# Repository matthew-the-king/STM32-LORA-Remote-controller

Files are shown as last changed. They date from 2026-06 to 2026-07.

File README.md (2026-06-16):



THE PROJECT
This is my LORA radio controller project! I wanted to make this because I am currently building a drone
that requires a capable LORA radio.
I have posted the Gerber files and BOM so you can produce your own functioning LORA radio controller.
The controller has two joysticks, two switches, and two potentiometers for inputs.  I also added
a buzzer to notify people when events happen, like connecting to a device.  In the PCB step file I added all the 3d 
models I could, but I could not get the potentiometer's 3d models. 

BUILDING 
To build this PCB, I would recommend ordering the PCB with a stencil because of the small and closely located parts on the board.
This PCB uses parts with pads exposed ONLY on the underside!
The PCB BOM does not include the REQUIRED RYLR998 LORA module; you can buy this on [Amazon](https://www.amazon.com/REYAX-RYLR998-Interface-Antenna-Transceiver/dp/B099RM1XMG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). 
Place the Lora module in these pins  with the correct orientation according to the labeled pin on the module.
Here is the BOM, but you can also find the BOM.csv file in the repository:
| Designator | Footprint | Qty | Value | LCSC Part # |
|---|---|-----|---|---|
| BT1 | PinHeader_1x02_P2.54mm_Vertical | 1 | Battery_Cell | |
| C1, C16 | 0402 | 2 | 10uF | |
| C10, C9 | 0603 | 2 | 18pF | |
| C11, C15, C2, C3, C4, C8 | 0402 | 6 | 0.1uF | |
| C12, C6, C7 | 0805 | 3 | 1uF | |
| C13, C14 | 0603 | 2 | 4.7uF | |
| C5 | 0603 | 1 | 10nF | |
| D1, D2 | 0805 | 2 | LED | |
| D3 | 0603 | 1 | LED | |
| D4, D5 | LED_D5.0mm | 2 | LED | |
| F1 | CP_EIA-3528-12_Kemet-T | 1 | 22uF | |
| J1 | SAMESKY_UJ20-C-H-G-SMT-1-P16-TR | 1 | USB-C | |
| J2 | PinHeader_1x05_P2.54mm_Vertical | 1 | Conn_01x05_Socket | |
| J3 | PinHeader_1x05_P2.54mm_Vertical | 1 | Conn_01x05_Pin | |
| J4 | PinHeader_1x03_P2.54mm_Vertical | 1 | Conn_01x03_Pin | |
| L1 | 0603 | 1 | 120R | |
| LS1 | SPKR_PKM22EPPH4001-B0 | 1 | PKM22EPPH4001-B0 | |
| Q1, Q2 | SOT-23 | 2 | BSS806N | |
| R1 | 0603 | 1 | 39 | |
| R10, R11 | 0402 | 2 | 1k | |
| R12 | 0603 | 1 | 49.9K | |
| R13 | 0402 | 1 | 200k | |
| R14 | 0402 | 1 | 1.13K | |
| R15, R16 | POT_P120PK-x25_TTE | 2 | P120PK | |
| R17, R18, R19, R6 | 0402 | 4 | 10k | |
| R2, R3 | 0402 | 2 | 5.1k | |
| R20, R21 | 1206 | 2 | 5M | |
| R22, R23, R8 | 0603 | 3 | 330 | |
| R4, R5 | 0402 | 2 | 22 | |
| R7 | 0603 | 1 | 2.2k | |
| R9 | 0402 | 1 | 1.18k | |
| S1, S2 | SW_200MSP1T2B4M2QE | 2 | 200MSP1T2B4M2QE | |
| U1 | UFQFPN-48_7X7X0P55MM | 1 | STM32F103CBU6 | |
| U2 | SON50P150X150X80-6N | 1 | BQ29700DSER | |
| U3, U4 | XDCR_COM-09032 | 2 | Joy_Stick | |
| U5 | SOT-23-6 | 1 | USBLC6-2SC6 | |
| U6 | SOT-223-3_TabPin2 | 1 | AMS1117-3.3 | |
| U7 | QFN50P300X300X100-17N | 1 | BQ24072TRGTR | |
| Y1 | XTAL_ECS-240-8-33-AGN-TR | 1 | ECS-80-12-33-JGN-TR | |

Once you complete your PCB, you can 3d print a case!  The case is only two parts, a Base and a top that can be screwed together with 4, 20mm screws, also the base has some holes for threaded inserts for m2.
Case_render

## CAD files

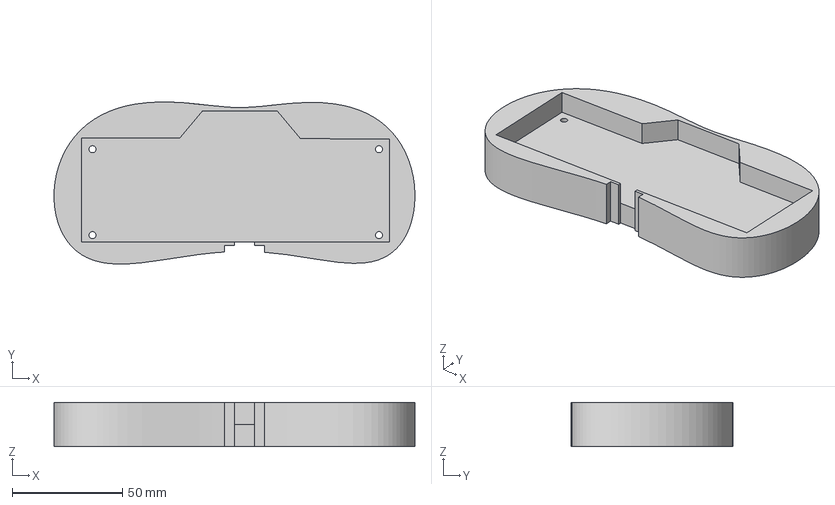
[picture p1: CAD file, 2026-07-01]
CAD/Radio_Controller_Base.step
163.8 x 73.6 x 20.0 mm

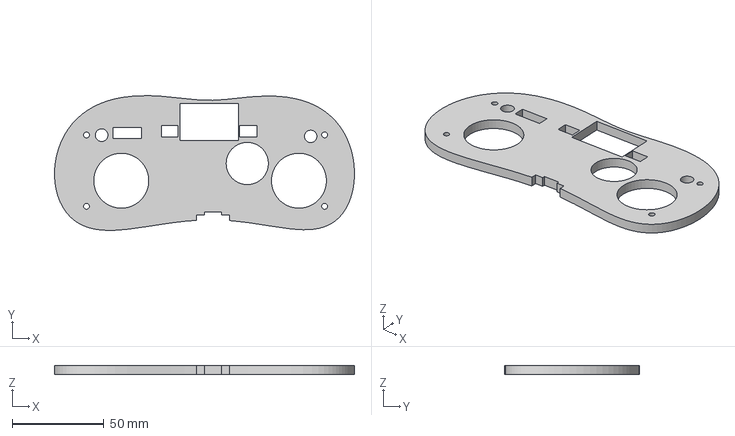
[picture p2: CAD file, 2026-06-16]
CAD/Controller_Top.step
163.8 x 73.6 x 5.00 mm

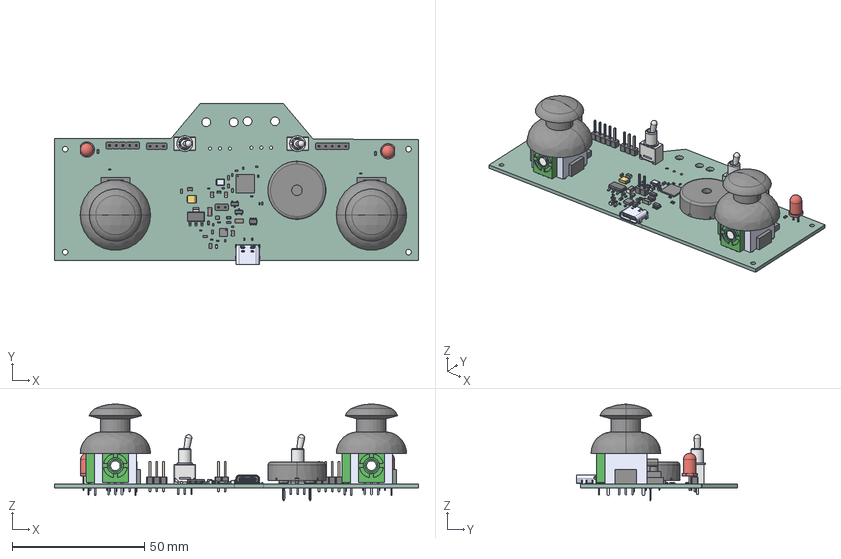
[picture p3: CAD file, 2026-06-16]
CAD/Radio_Controller.step
137.8 x 60.9 x 36.7 mm
C_0402_1005Metric x 21
C_0603_1608Metric x 9
COM-09032 x 2
LED_D5.0mm x 2
ECS-80-12-33-JGN-TR
SOT-223
SOT-23 x 2
BQ24072TRGTR
PinHeader_1x05_P2.54mm_Vertical x 2
R_0603_1608Metric x 3
C_0805_2012Metric x 5
PinHeader_1x03_P2.54mm_Vertical
PinHeader_1x02_P2.54mm_Vertical
QFN50P700X700X60-49N
PKM22EPPH4001-B0
C_1206_3216Metric x 2
CP_EIA-3528-12_Kemet-T
LED_0603_1608Metric
SOT-23-6
200MSP1T2B4M2QE x 2
BQ29700DSER
UJ20-C-H-G-SMT-1-P16-TR_UJ20-C-H-G-SMT-1-P16-TR
Radio_Controller_PCB

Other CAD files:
CAD/Controller_Base.step

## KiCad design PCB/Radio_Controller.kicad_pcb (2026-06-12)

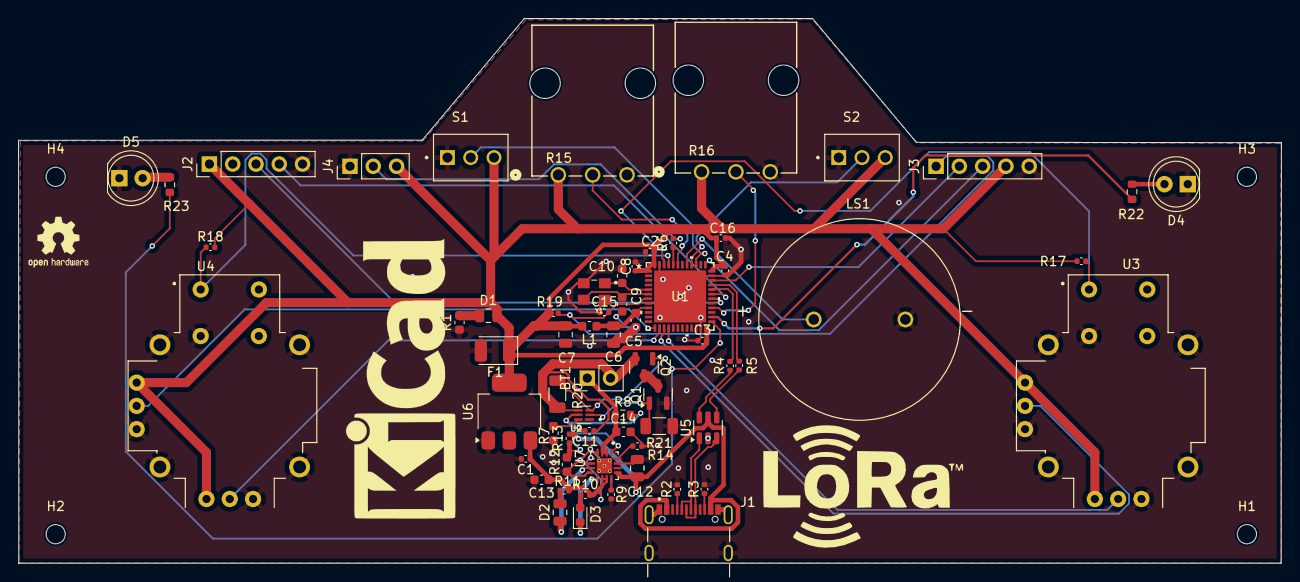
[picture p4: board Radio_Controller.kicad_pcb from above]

Board: 2 copper layers, 137.8 x 59.4 mm, 68 parts (0 on the bottom side), 52 nets.

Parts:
BT1: Battery_Cell; PinHeader_1x02_P2.54mm_Vertical
C1, C16: 10uF; C_0402_1005Metric
C2, C3, C4, C8, C11, C15: 0.1uF; C_0402_1005Metric
C5: 10nF; C_0603_1608Metric
C6, C7, C12: 1uF; C_0805_2012Metric
C9, C10: 18pF; C_0603_1608Metric
C13, C14: 4.7uF; C_0603_1608Metric
D1, D2: LED; C_0805_2012Metric
D3: LED; LED_0603_1608Metric
D4, D5: LED; LED_D5.0mm
F1: 22uF; CP_EIA-3528-12_Kemet-T
H1, H2, H3, H4: MountingHole; MountingHole_2.1mm
J1: USB-C; SAMESKY_UJ20-C-H-G-SMT-1-P16-TR
J2: Conn_01x05_Socket; PinHeader_1x05_P2.54mm_Vertical
J3: Conn_01x05_Pin; PinHeader_1x05_P2.54mm_Vertical
J4: Conn_01x03_Pin; PinHeader_1x03_P2.54mm_Vertical
L1: 120R; C_0603_1608Metric
LS1: PKM22EPPH4001-B0; SPKR_PKM22EPPH4001-B0
Q1, Q2: BSS806N; SOT-23
R1: 39; C_0603_1608Metric
R2, R3: 5.1k; C_0402_1005Metric
R4, R5: 22; C_0402_1005Metric
R6, R17, R18, R19: 10k; C_0402_1005Metric
R7: 2.2k; C_0603_1608Metric
R8, R22, R23: 330; R_0603_1608Metric
R9: 1.18k; C_0402_1005Metric
R10, R11: 1k; C_0402_1005Metric
R12: 49.9K; C_0603_1608Metric
R13: 200k; C_0402_1005Metric
R14: 1.13K; C_0402_1005Metric
R15, R16: P120PK; POT_P120PK-x25_TTE
R20, R21: 5M; C_1206_3216Metric
S1, S2: 200MSP1T2B4M2QE; SW_200MSP1T2B4M2QE
U1: STM32F103CBU6; UFQFPN-48_7X7X0P55MM
U2: BQ29700DSER; SON50P150X150X80-6N
U3, U4: Joy_Stick; XDCR_COM-09032
U5: USBLC6-2SC6; SOT-23-6
U6: AMS1117-3.3; SOT-223-3_TabPin2
U7: BQ24072TRGTR; QFN50P300X300X100-17N
Y1: ECS-80-12-33-JGN-TR; XTAL_ECS-240-8-33-AGN-TR

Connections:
+3.3V: C2.2, C3.2, C4.2, C7.1, C8.2, C16.2, D1.2 (A), F1.1, J2.1, J3.4, J4.3, L1.2, R15.1, R16.1, R17.2, R18.2, R19.2, S1.3, S2.3, U1.1 (VBAT), U1.24 (VDD_1), U1.36 (VDD_2), U1.48 (VDD_3), U3.H1 (H+), U3.V1 (V+), U4.H1 (H+), U4.V1 (V+), U6.2 (VO)
BOOT0: J4.2, R6.2
D+: R5.2, U1.33 (PA12)
D-: R4.2, U1.32 (PA11)
GND: C1.2, C2.1, C3.1, C4.1, C5.2, C6.2, C7.2, C8.1, C9.1, C10.1, C12.2, C13.2, C14.2, C15.1, C16.1, D4.1 (K), D5.1 (K), F1.2, J1.A1_B12 (GND), J1.B1_A12 (GND__1), J1.SH1 (SHIELD), J1.SH2 (SHIELD__1), J1.SH3 (SHIELD__2), J1.SH4 (SHIELD__3), J2.5, J3.5, J4.1, LS1.N, Q1.2 (S), R1.1, R2.2, R3.2, R7.1, R9.2, R12.2, R14.2, R15.3, R16.3, R21.1, S1.1, S2.1, U1.8 (VSSA), U1.23 (VSS_1), U1.35 (VSS_2), U1.47 (VSS_3), U1.49 (EPAD), U3.B2A (SEL-), U3.H3 (H-), U3.S1 (SHIELD), U3.S2 (SHIELD__1), U3.S3 (SHIELD__2), U3.S4 (SHIELD__3), U3.V3 (V-), U4.B2A (SEL-), U4.H3 (H-), U4.S1 (SHIELD), U4.S2 (SHIELD__1), U4.S3 (SHIELD__2), U4.S4 (SHIELD__3), U4.V3 (V-), U5.2 (GND), U6.1 (GND), U7.4 (~CE), U7.6 (EN1), U7.8 (VSS), U7.15 (TD), U7.17 (EP), Y1.2 (GND), Y1.4 (GND__1)
H1: U1.14 (PA4), U4.H2 (H)
H2: U1.16 (PA6), U3.H2 (H)
NRST: C15.2, J3.1, R19.1, U1.7 (NRST)
unnamed: BT1.2 (-), C11.2, Q2.2 (S), R20.2, U2.4 (VSS)
unnamed: D1.1 (K), R1.2
unnamed: D2.2 (A), R11.1
unnamed: D2.1 (K), U7.7 (~PGOOD)
unnamed: D3.2 (A), R10.1
unnamed: D3.1 (K), U7.9 (~CHG)
unnamed: D4.2 (A), R22.1
unnamed: D5.2 (A), R23.2
unnamed: J1.A5 (CC1), R2.1
unnamed: J1.B5 (CC2), R3.1
unnamed: J1.A7 (DN1), J1.B7 (DN2), U5.1 (I/O1)
unnamed: J1.A6 (DP1), J1.B6 (DP2), U5.3 (I/O2)
unnamed: Q1.3 (D), Q2.3 (D)
unnamed: Q1.1 (G), R21.2, U2.2 (COUT)
unnamed: Q2.1 (G), R20.1, U2.3 (DOUT)
unnamed: R4.1, U5.6 (I/O1)
unnamed: R5.1, U5.4 (I/O2)
unnamed: R6.1, U1.44 (BOOT0)
unnamed: S1.2, U1.39 (PB3)
unnamed: S2.2, U1.40 (PB4)
unnamed: LS1.P, U1.41 (PB5)
unnamed: R15.2, U1.43 (PB7)
unnamed: R23.1, U1.25 (PB12)
unnamed: R22.2, U1.26 (PB13)
unnamed: R16.2, U1.28 (PB15)
unnamed: C5.1, C6.1, L1.1, U1.9 (VDDA)
unnamed: C11.1, R8.2, U2.5 (BAT)
unnamed: R7.2, U2.6 (V-)
unnamed: R9.1, U7.12 (ILIM)
unnamed: R14.1, U7.16 (ISET)
unnamed: R12.1, R13.2, U7.1 (TS)
OSC_IN: C10.2, U1.5 (OSC_IN), Y1.1 (IN/OUT)
OSC_OUT: C9.2, U1.6 (OSC_OUT), Y1.3 (OUT/IN)
OUT: C1.1, C13.1, R10.2, R11.2, U6.3 (VI), U7.5 (EN2), U7.10 (OUT), U7.11 (OUT__1)
Pack+: BT1.1 (+), C14.1, R8.1, U7.2 (BAT), U7.3 (BAT__1)
RX: J2.3, U1.30 (PA9)
SEL1: R18.1, U1.45 (PB8), U4.B1A (SEL+)
SEL2: R17.1, U1.46 (PB9), U3.B1A (SEL+)
SWCLK: J3.3, U1.37 (PA14)
SWDIO: J3.2, U1.34 (PA13)
TX: J2.4, U1.31 (PA10)
V1: U1.13 (PA3), U4.V2 (V)
V2: U1.15 (PA5), U3.V2 (V)
VBUS: C12.1, J1.A4_B9 (VBUS), J1.B4_A9 (VBUS__1), R13.1, U5.5 (VBUS), U7.13 (IN)

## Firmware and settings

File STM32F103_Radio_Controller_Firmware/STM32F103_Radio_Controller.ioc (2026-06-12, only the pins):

Mcu.UserName=STM32F103CBUx
PA10.Signal=USART1_RX
PA11.Signal=USB_DM
PA12.Signal=USB_DP
PA13.Signal=SYS_JTMS-SWDIO
PA14.Signal=SYS_JTCK-SWCLK
PA3.Signal=ADCx_IN3
PA4.Signal=ADCx_IN4
PA5.Signal=ADCx_IN5
PA6.Signal=ADCx_IN6
PA9.Signal=USART1_TX
PB3.Signal=GPIO_Input
PB4.Signal=GPIO_Input
PD0-OSC_IN.Signal=RCC_OSC_IN
PD1-OSC_OUT.Signal=RCC_OSC_OUT

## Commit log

2026-06-11 PCB files
    [bom.csv, designators.csv, positions.csv]
2026-06-12 Enhance README with project details and BOM
    Added detailed project description and BOM table.
2026-06-12 Enhance README with BOM details
    Added detailed BOM table with component specifications.
2026-06-12 Organize files
    [Radio_Controller.kicad_pcb, Radio_Controller_Base.stl, Radio_Controller_Shell_Top.stl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]
2026-06-12 Added CAD back
    [Radio_Controller_Base.stl, Radio_Controller_Shell_Top.stl]
2026-06-16 switched PCB cad into CAD folder
    [Radio_Controller.step]
2026-06-16 Update README with project details and case design
    Added details about the project, including the case design and 3D models.
2026-06-16 Fix punctuation in case assembly instructions
2026-06-16 delted STL files for STEP files
    [Radio_Controller_Base.stl, Radio_Controller_Shell.stl, Radio_Controller_Shell_Top.stl]
2026-07-01 new base step file
    [Radio_Controller_Base.step]
